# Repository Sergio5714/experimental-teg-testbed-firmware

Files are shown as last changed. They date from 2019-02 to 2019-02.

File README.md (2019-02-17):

# Experimental TEG (thermoelectric generator) testbed firmware
**Author: Sergei Vostrikov**

This repository contains embedded software and the PCBs for the experimental testbed.

**The main function of the testbed:**
* Imitate heat exchange, thermoelectric and electric proceses 
in the wearable thermoelectric generator.

**Testbed's subsystems enable:**
* Low speed (>= _5 Hz_) temperature measurements with an accuracy better than _0.15°K_;
* Temperature difference stabilization (temperature swing <=_12°K_, stabilization error <= _0.1°K_);
* Two channels ADC measurements (accuracy >= _1 mv_) in a range of approximately _0 - 100 mV_;
* Real time [data visialization](https://github.com/Sergio5714/experimental-teg-testbed-gui).

**Used technologies/tools:** C, Keil uVision, STM32F4, FreeRTOS, Jupyter, KiCAD, Peltier modules.

Detailed description can be found in the 
[pdf manual](https://github.com/Sergio5714/experimental-teg-testbed-firmware/blob/master/docs/Description_experimental_teg_testbed.pdf).

**The main PCB:**



**The temperature sensor PCB:**

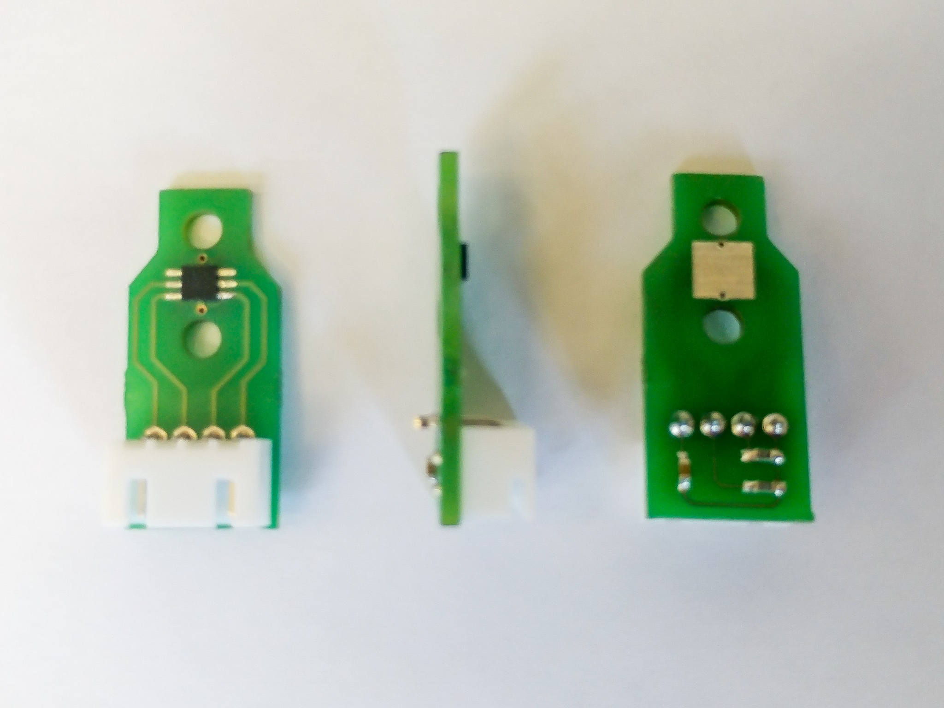
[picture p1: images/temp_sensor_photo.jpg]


**The testbed simplified schematic:**

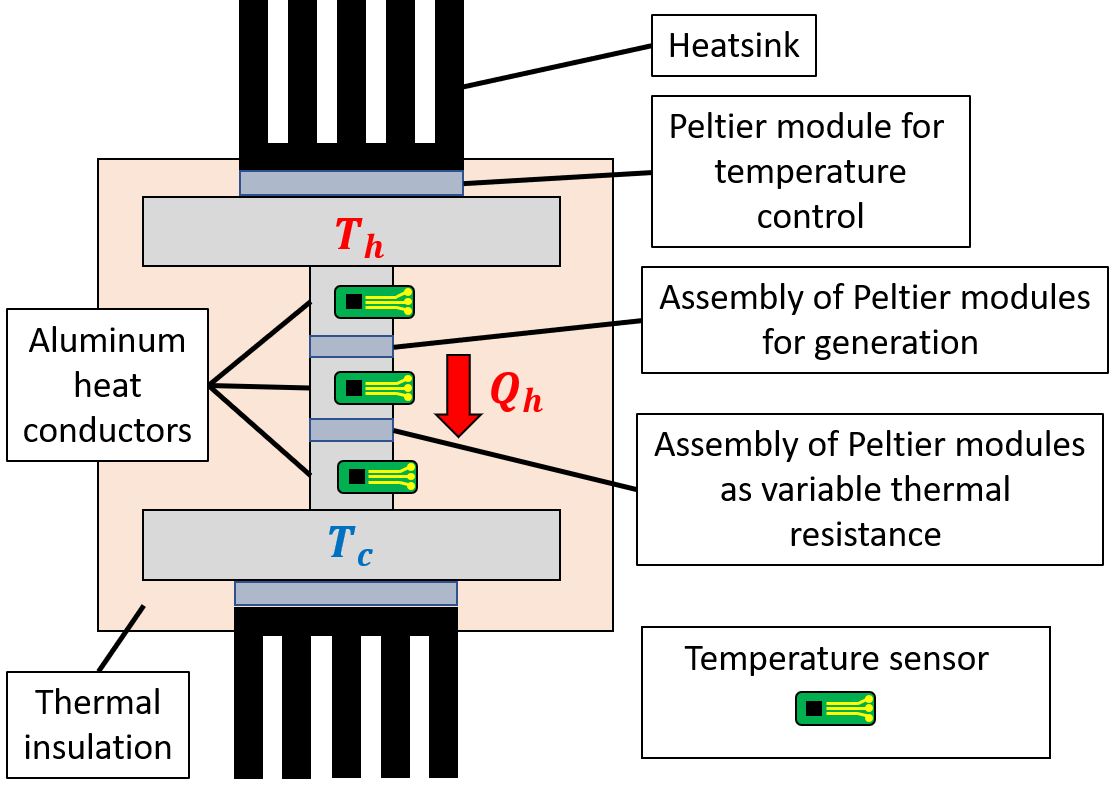
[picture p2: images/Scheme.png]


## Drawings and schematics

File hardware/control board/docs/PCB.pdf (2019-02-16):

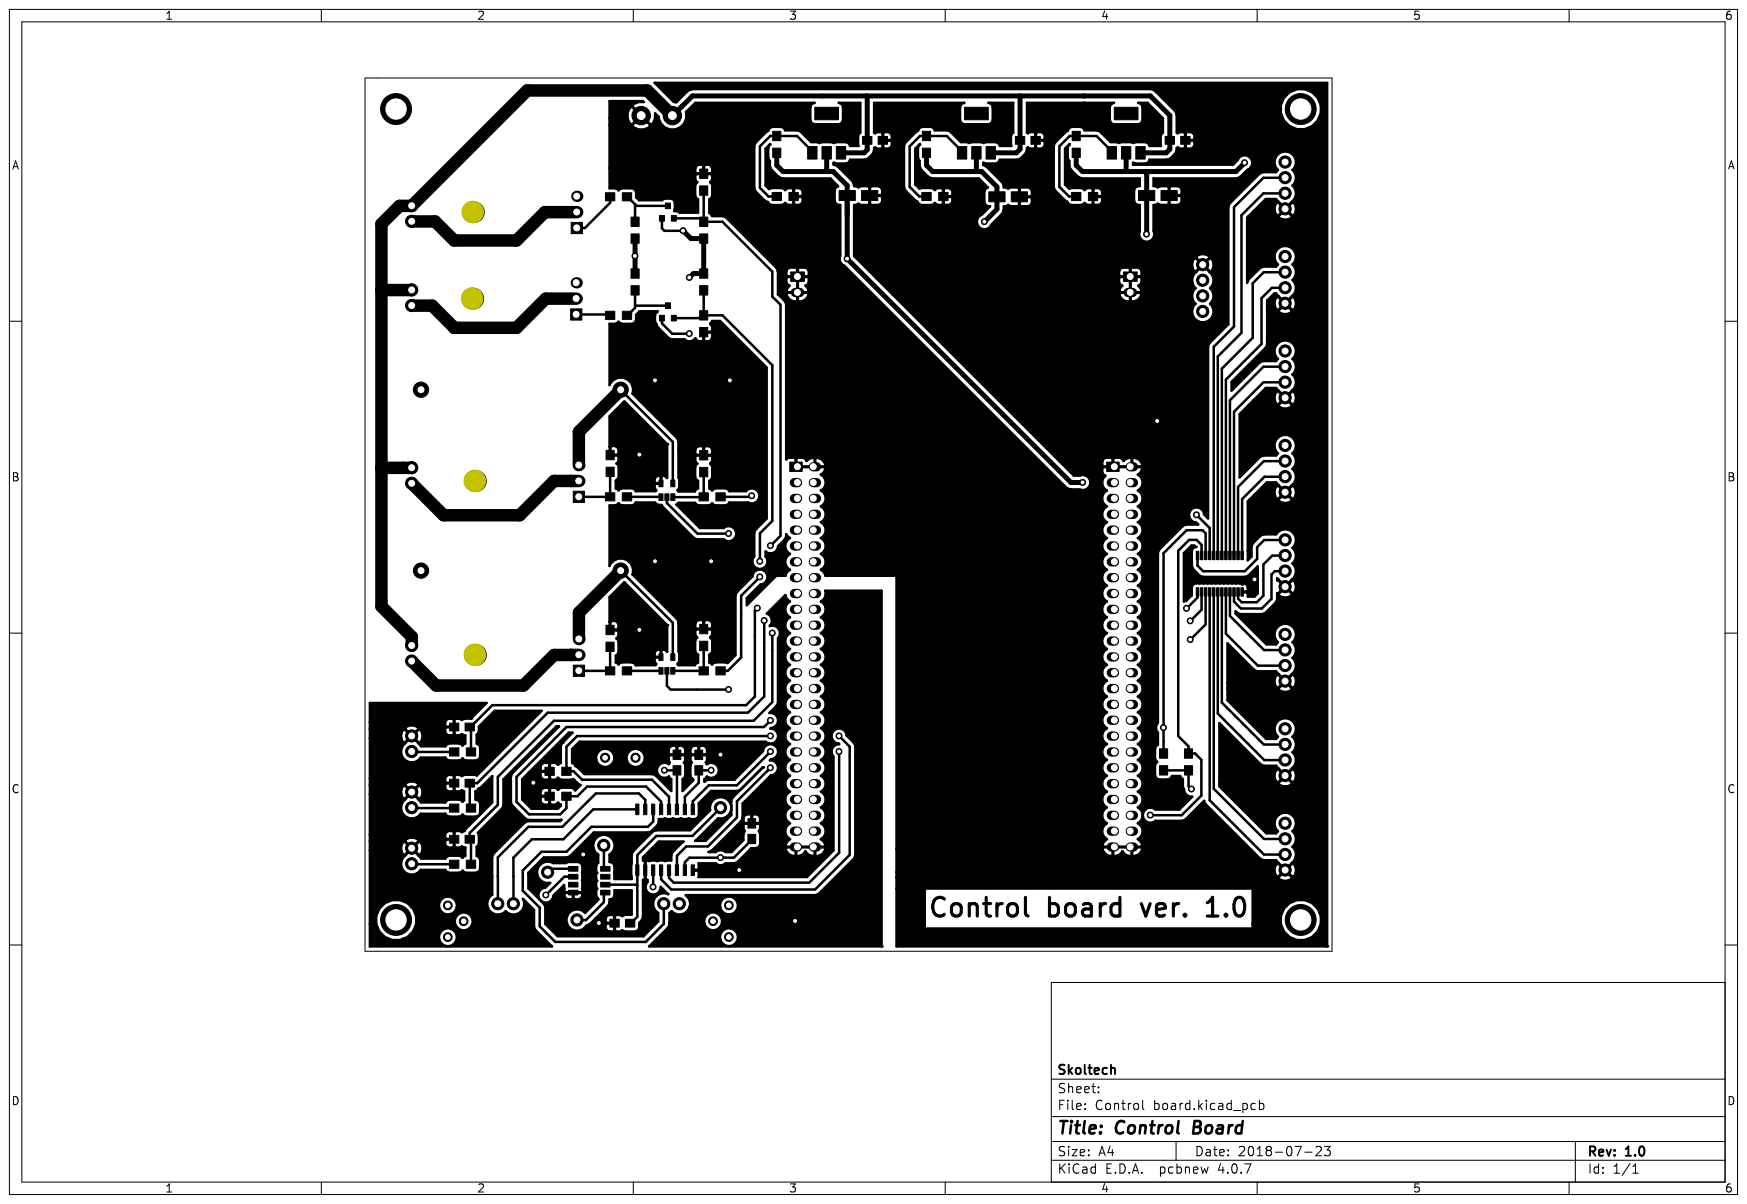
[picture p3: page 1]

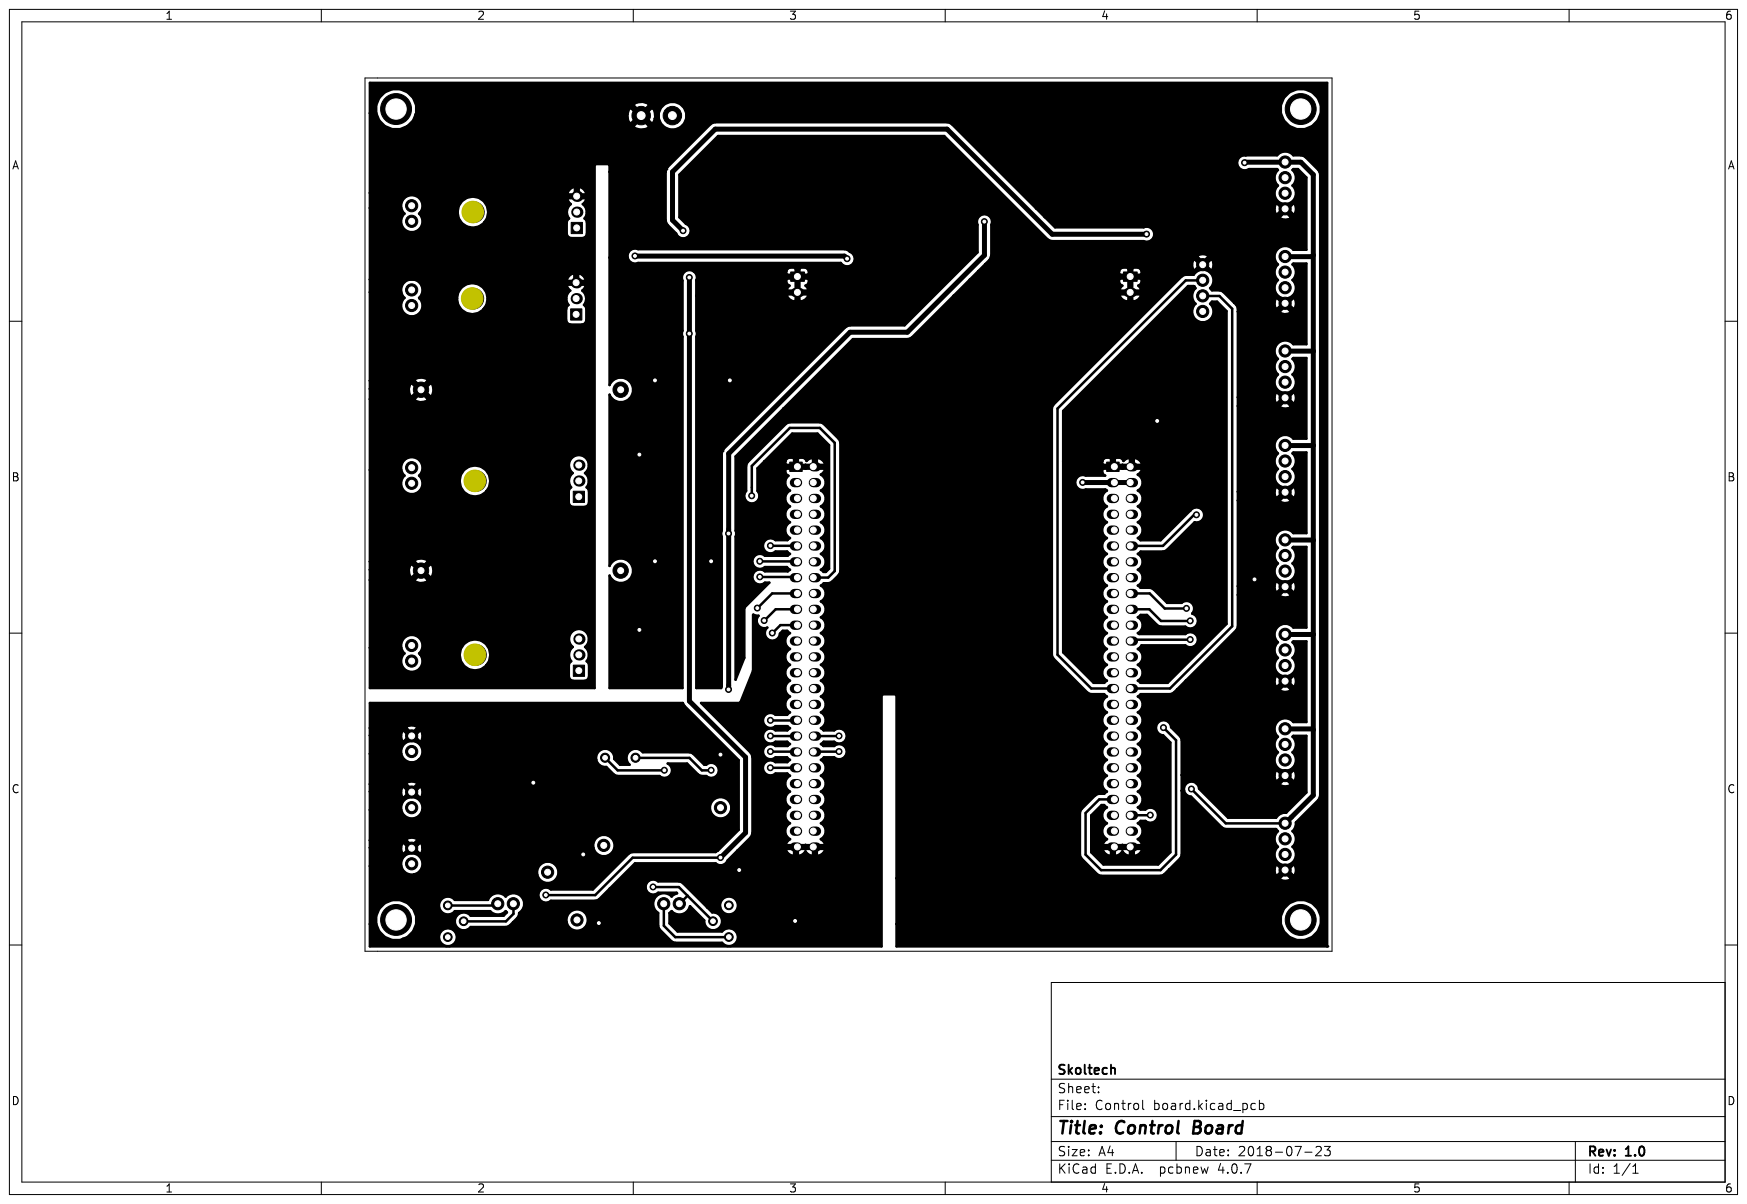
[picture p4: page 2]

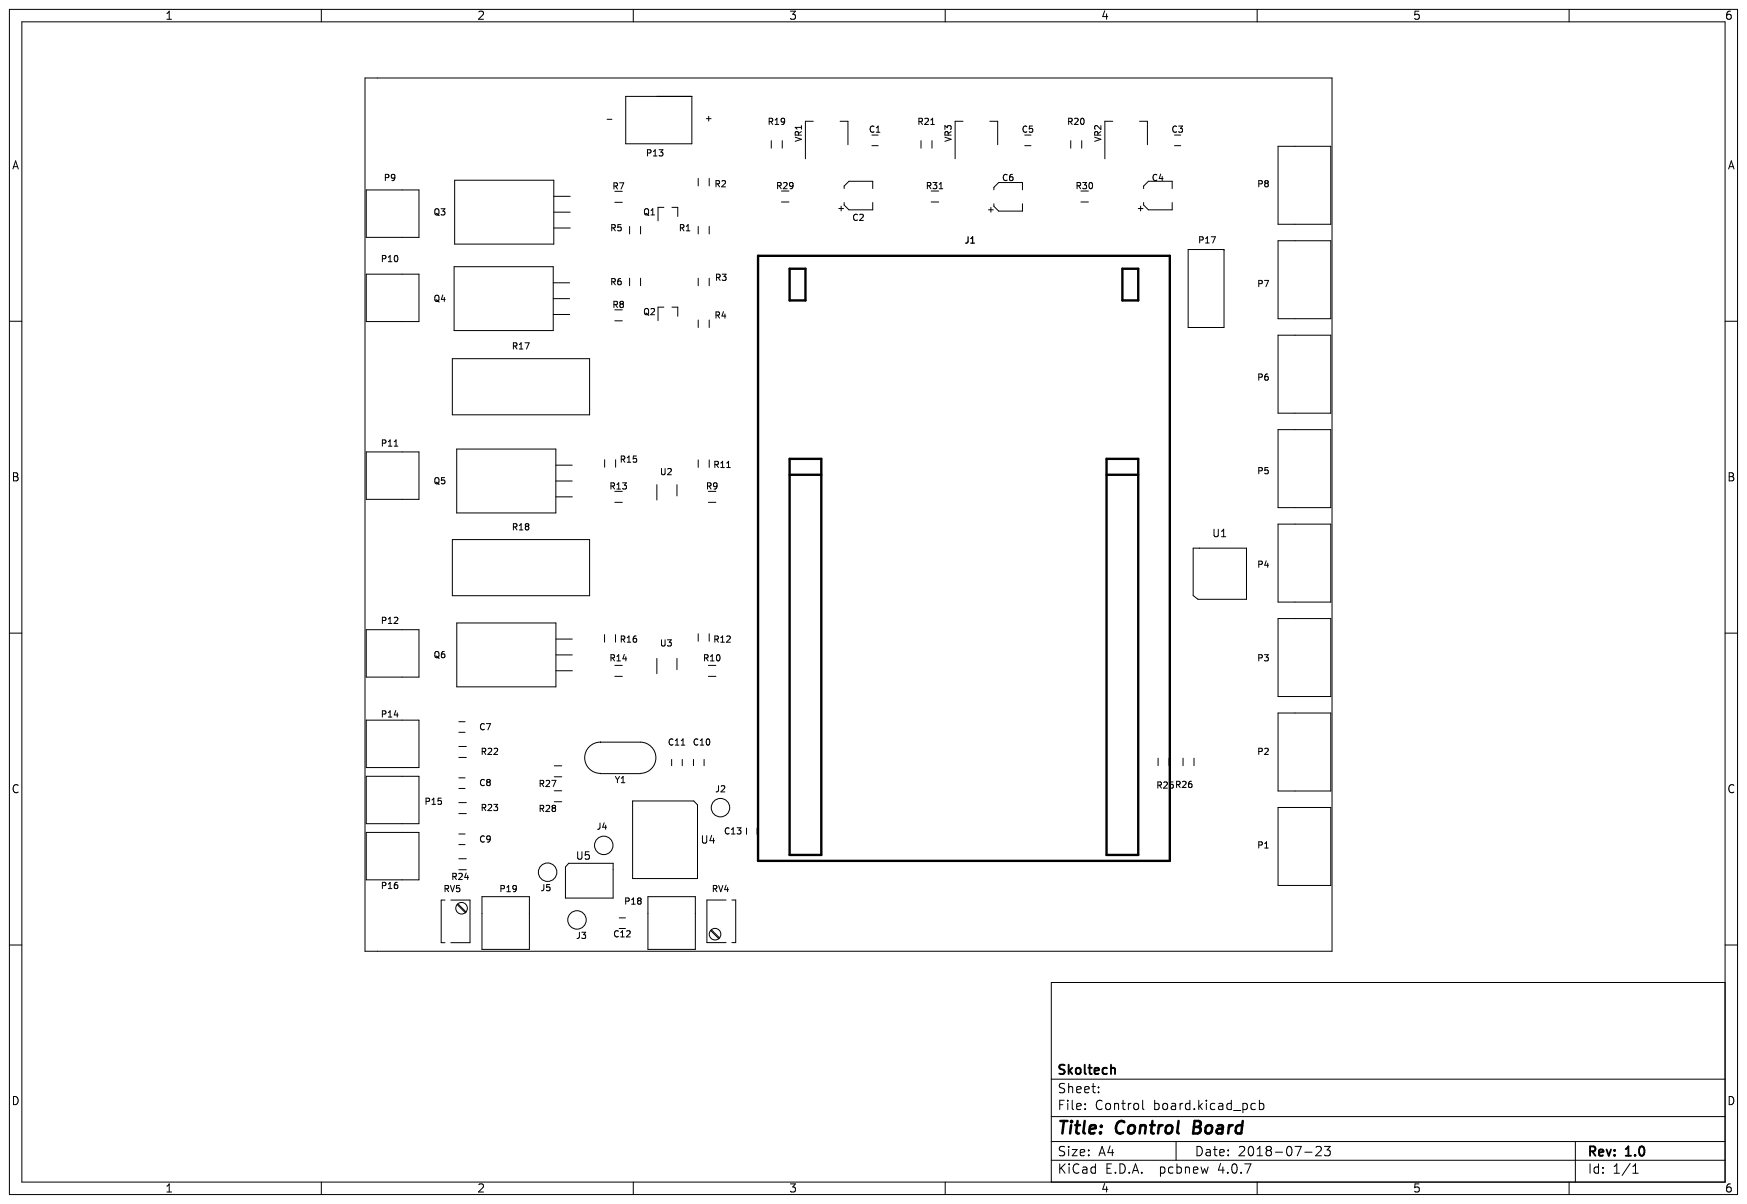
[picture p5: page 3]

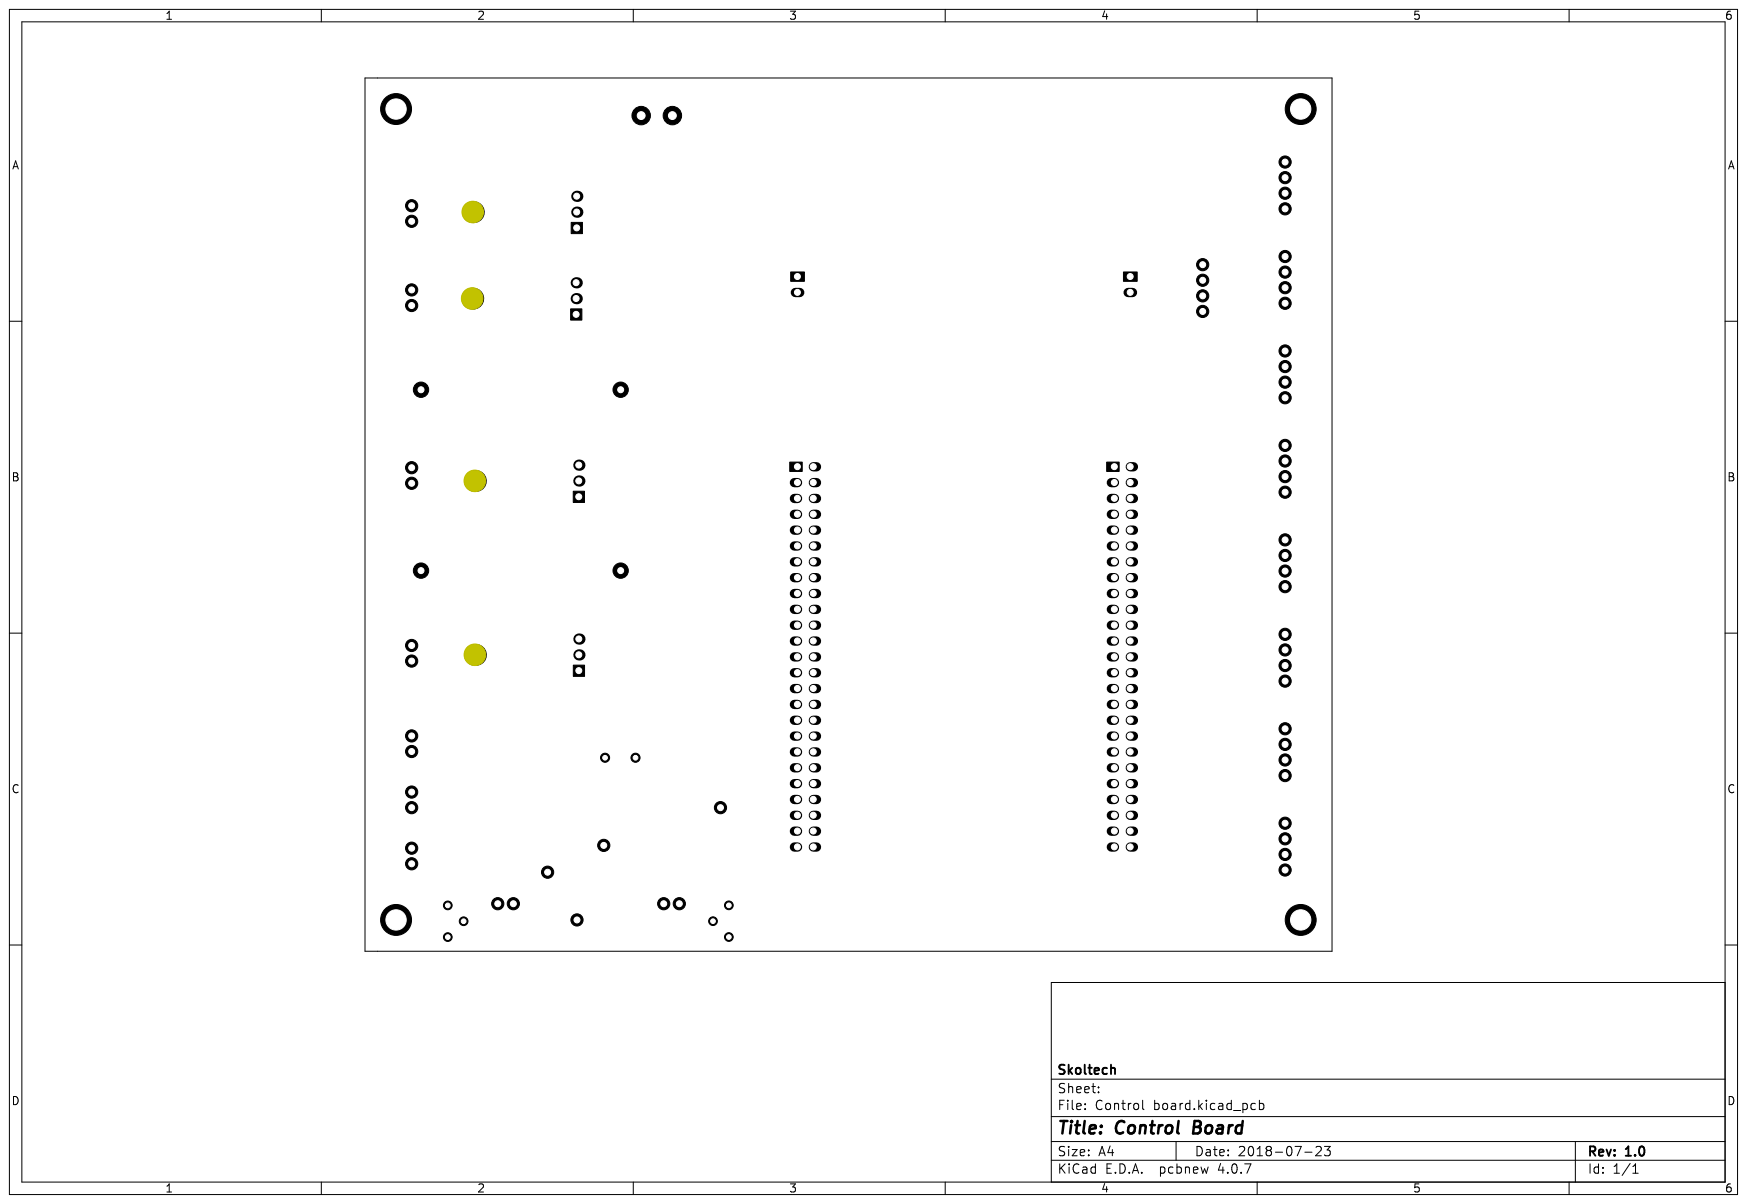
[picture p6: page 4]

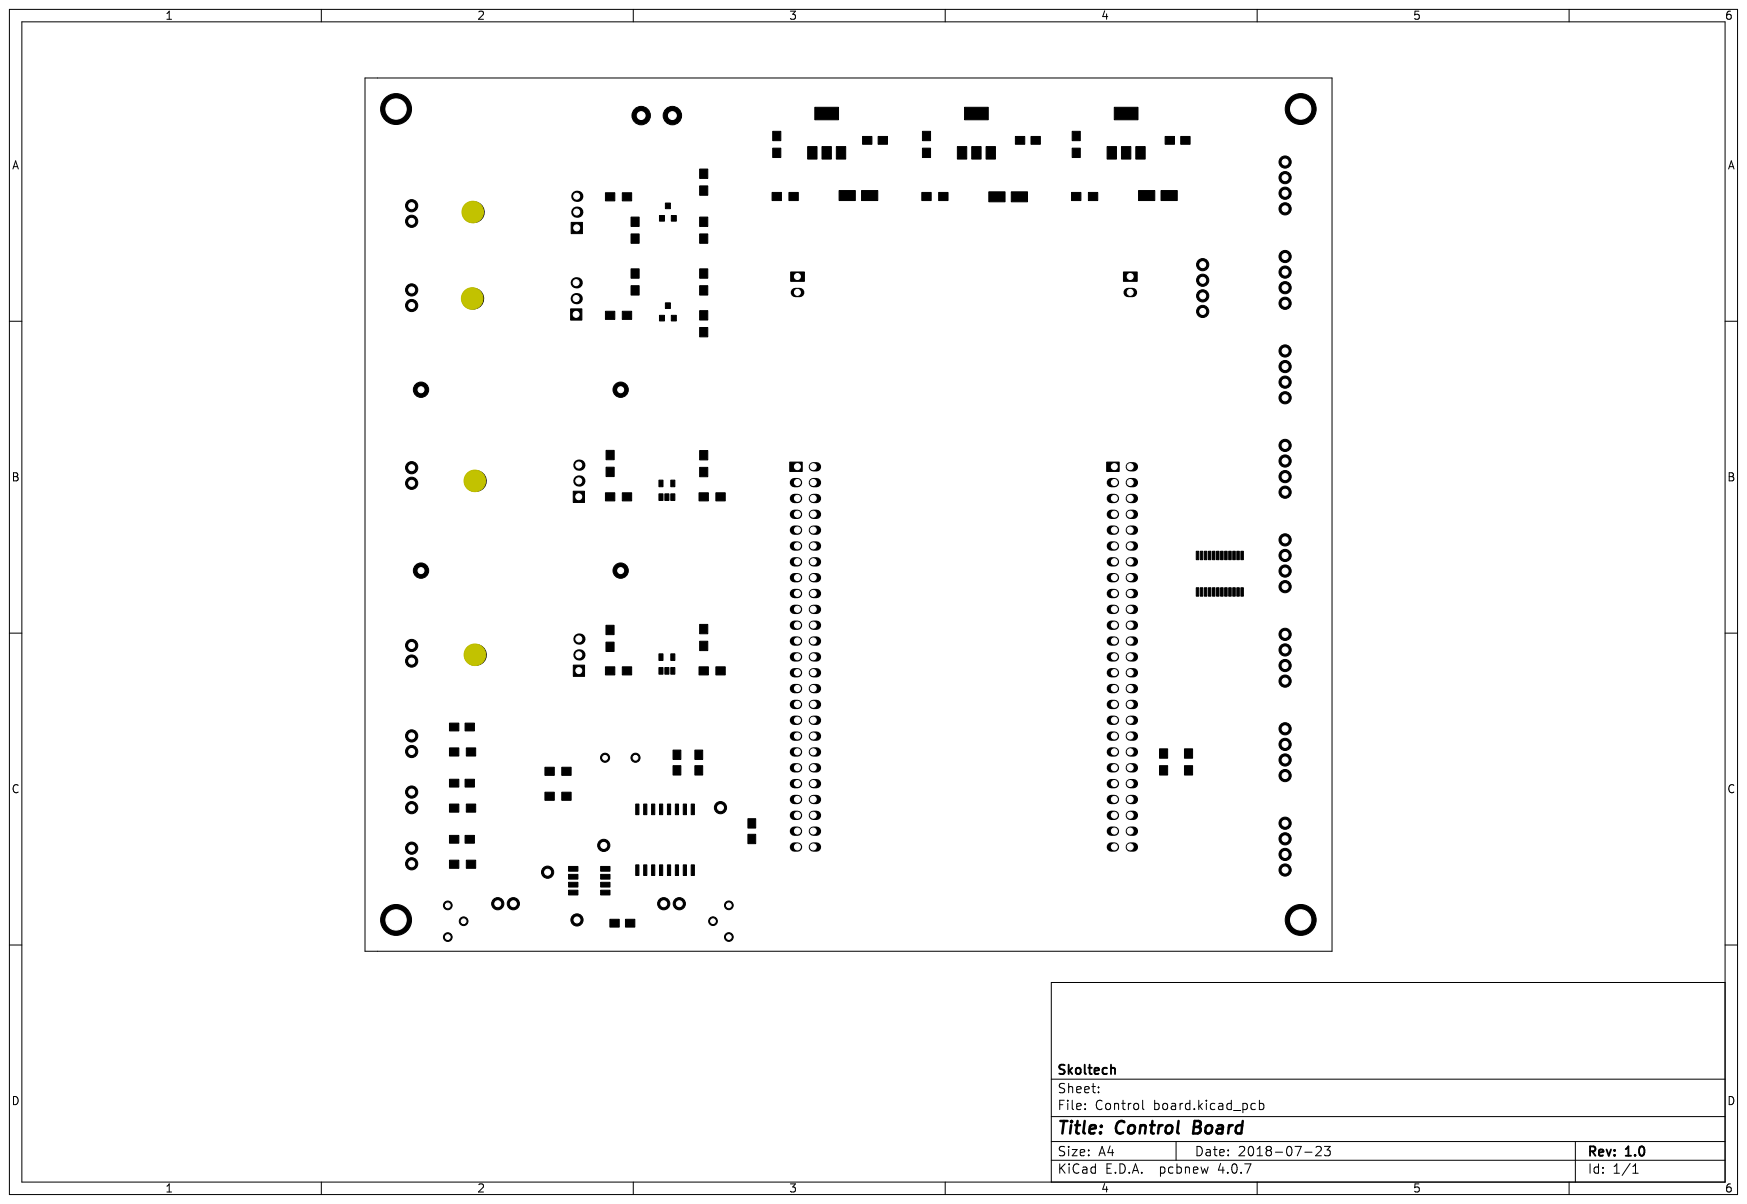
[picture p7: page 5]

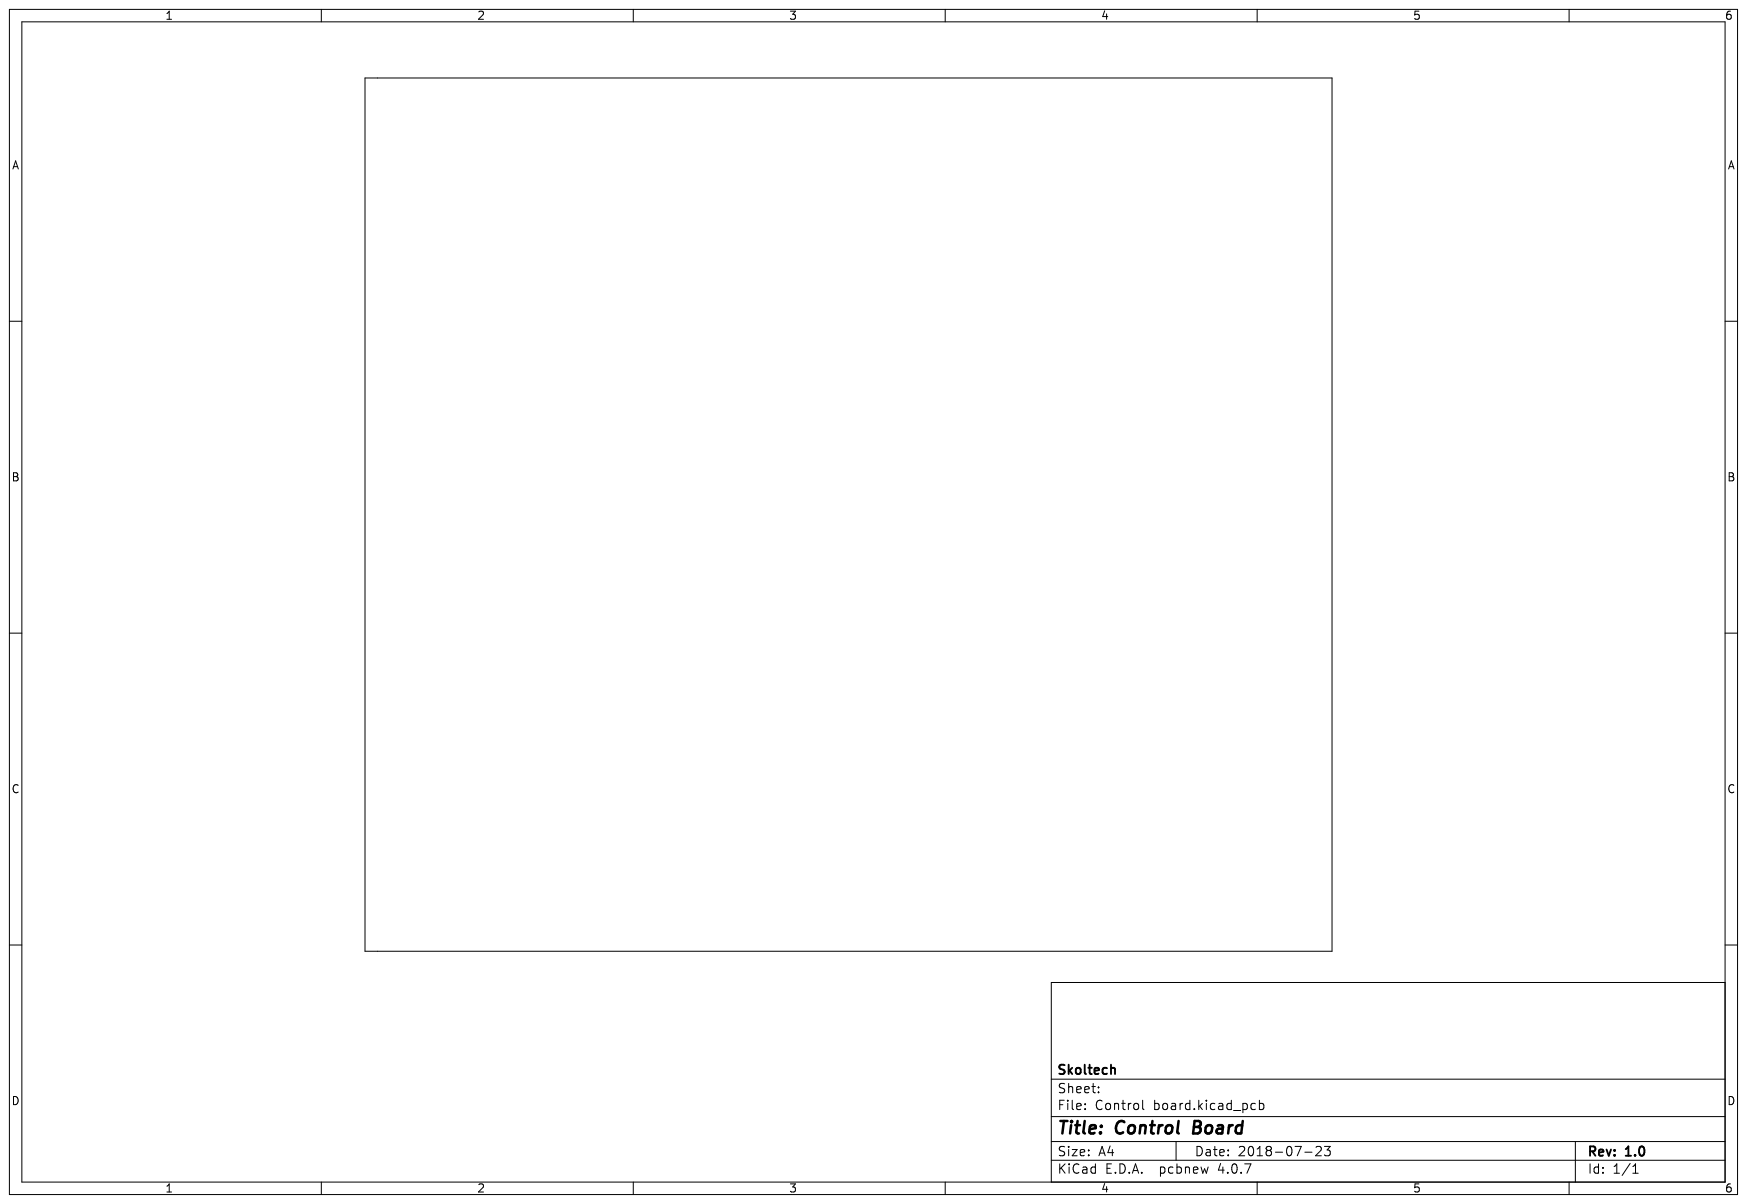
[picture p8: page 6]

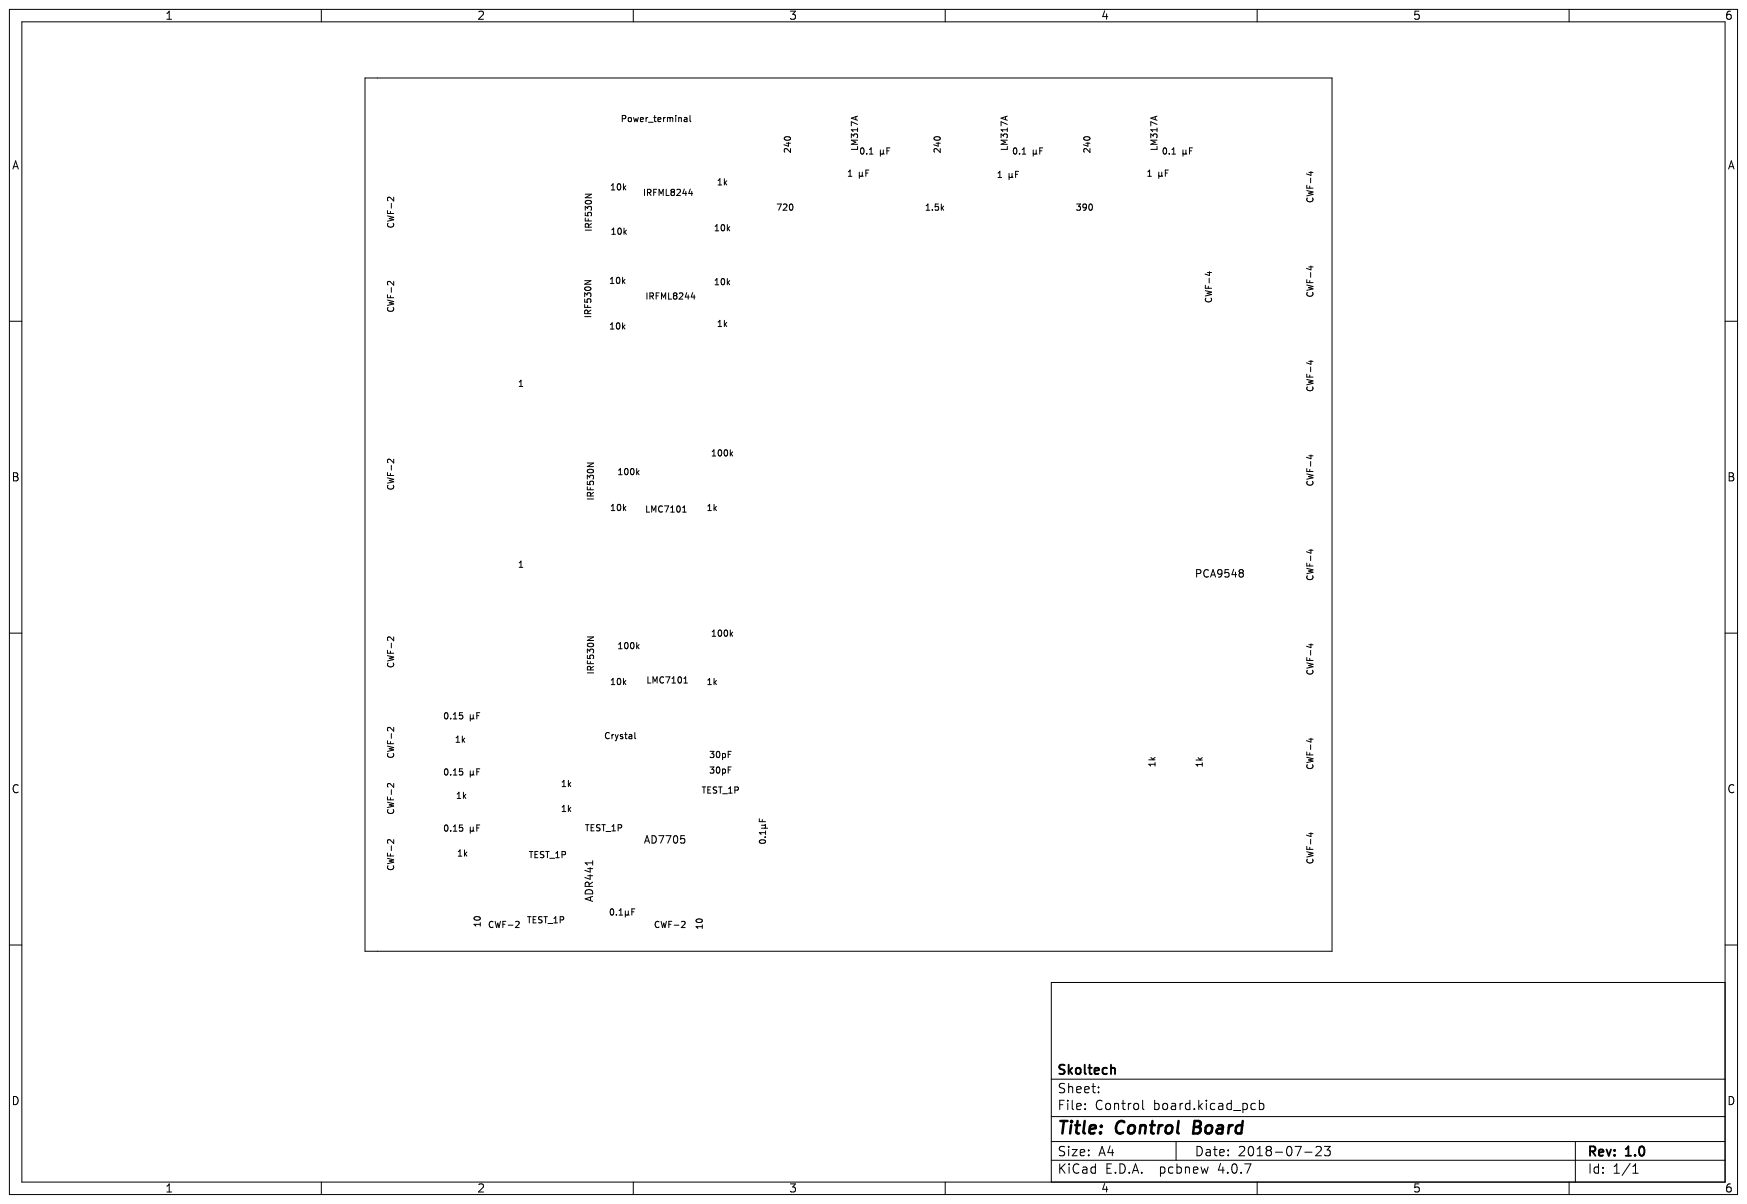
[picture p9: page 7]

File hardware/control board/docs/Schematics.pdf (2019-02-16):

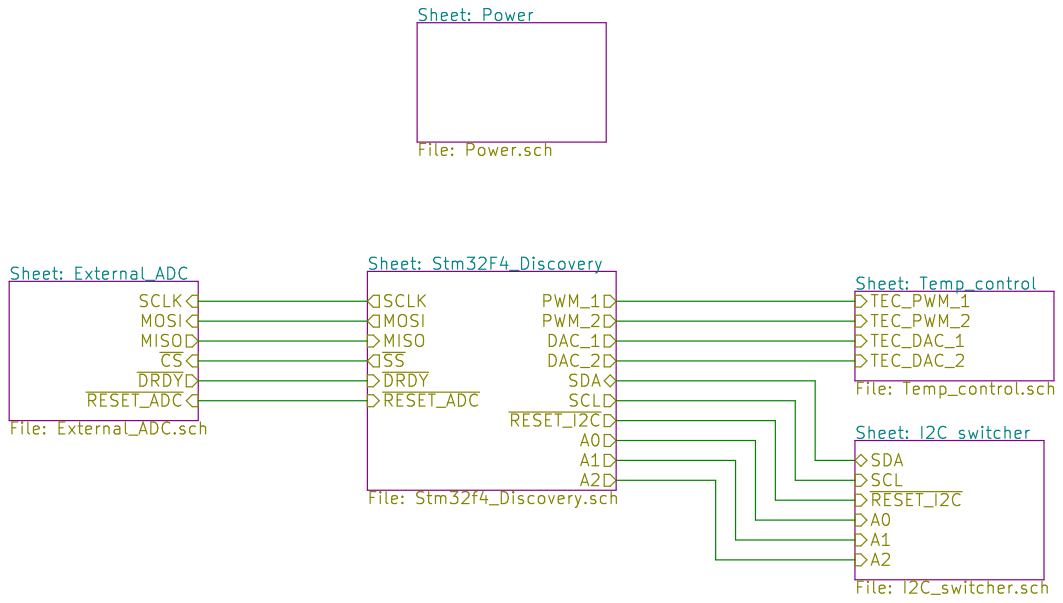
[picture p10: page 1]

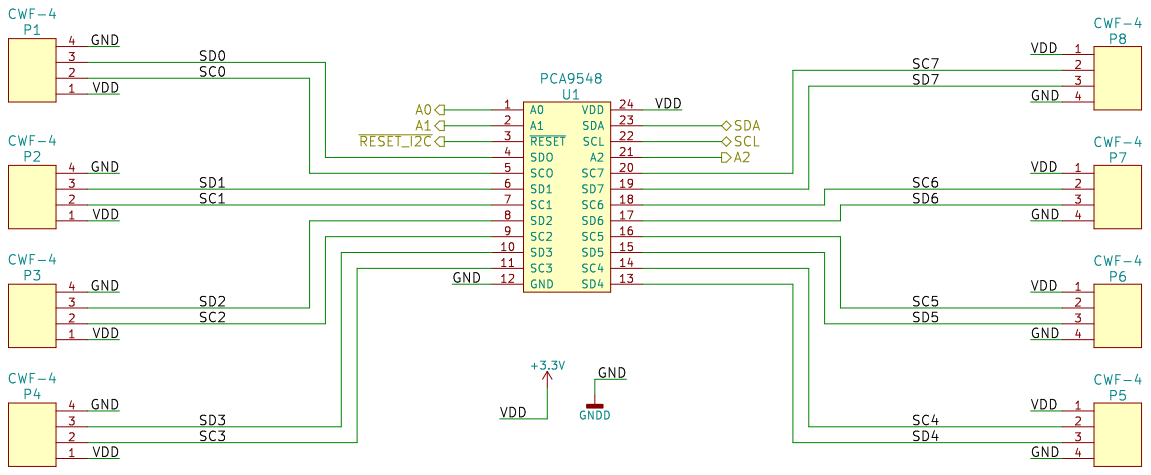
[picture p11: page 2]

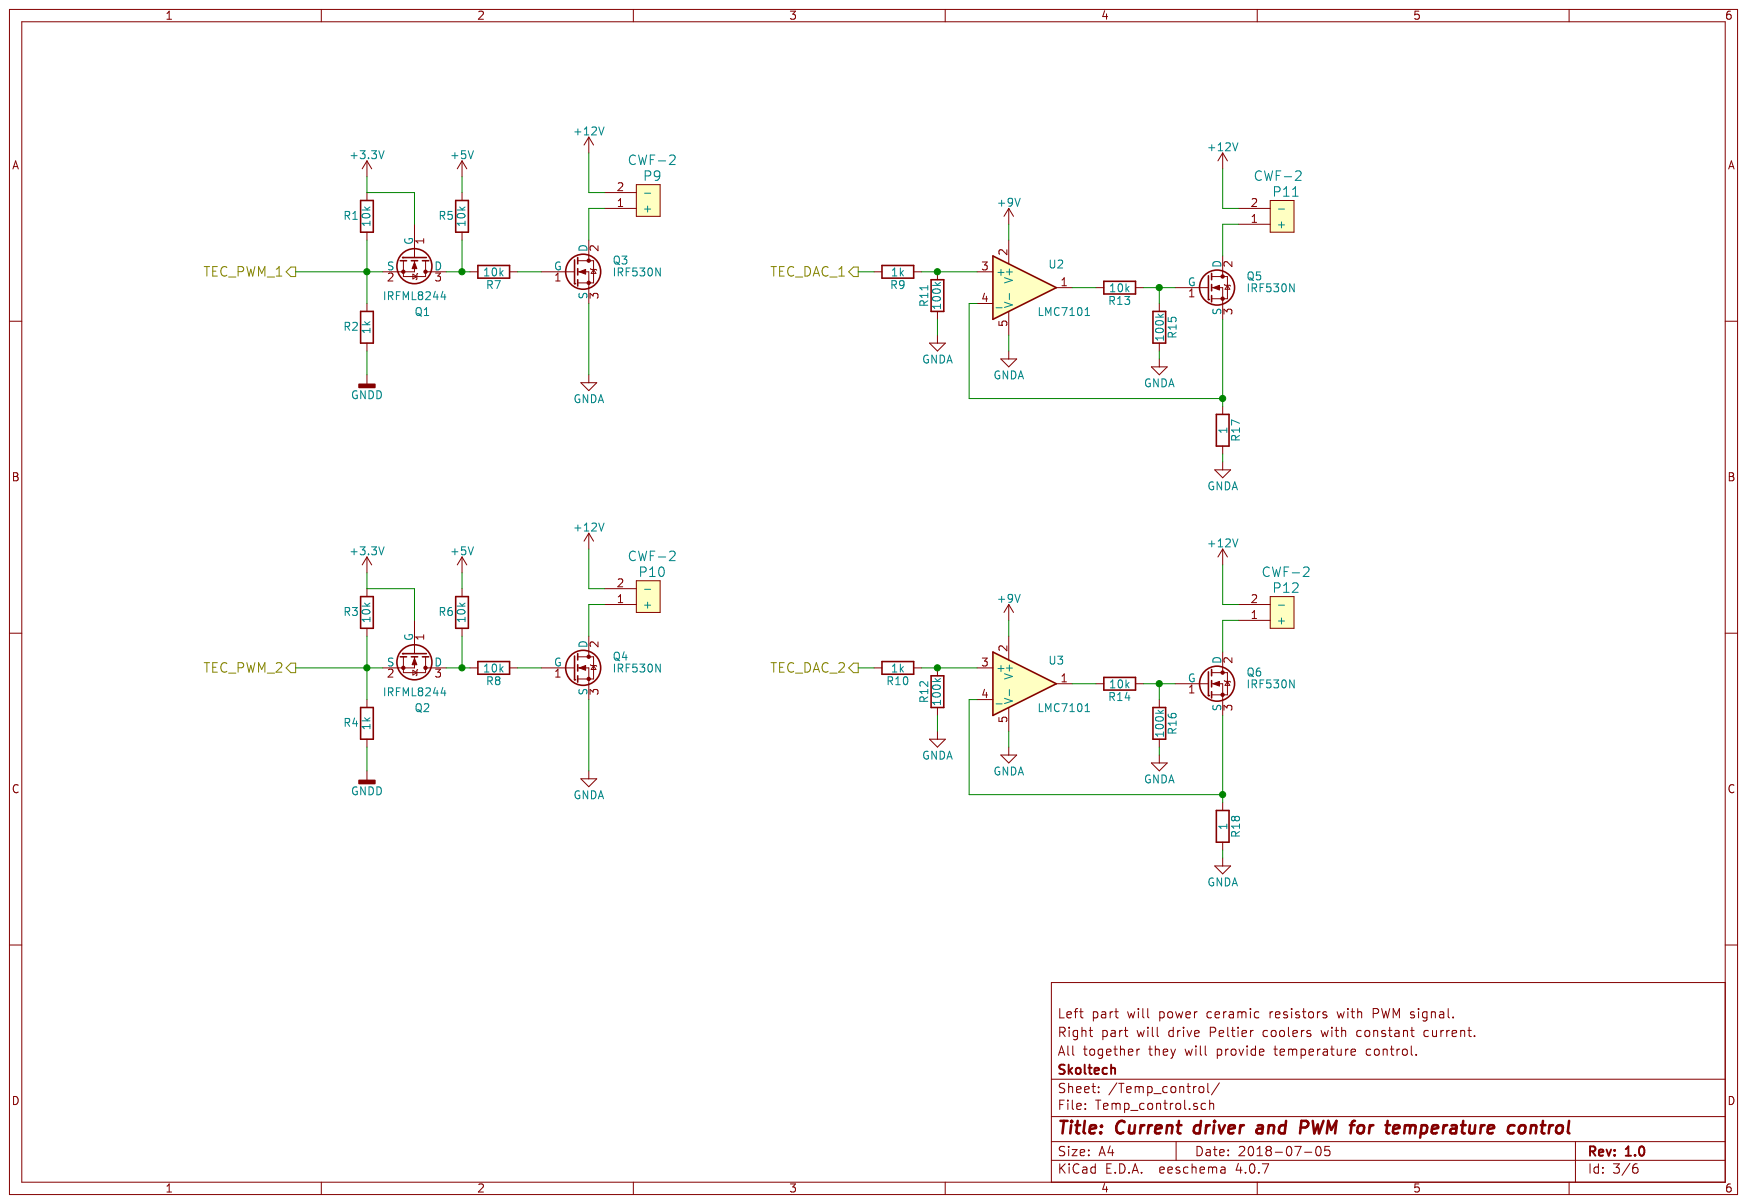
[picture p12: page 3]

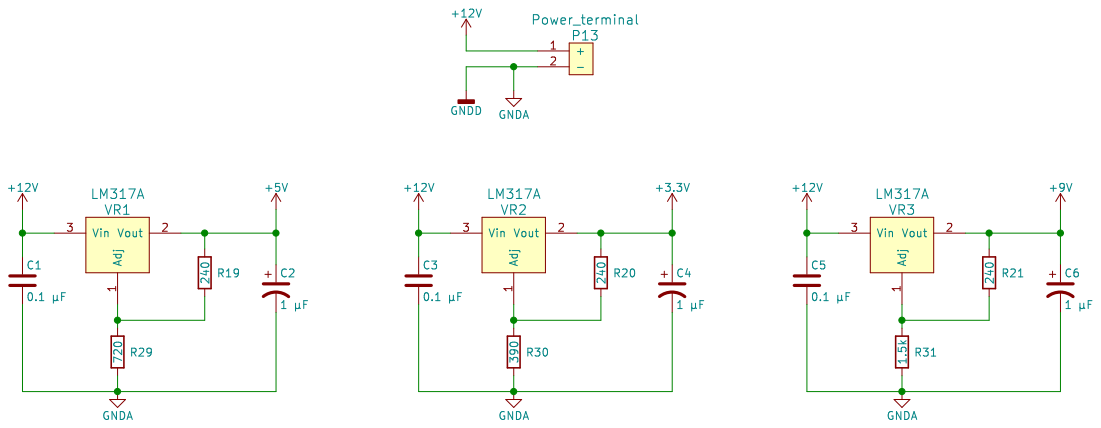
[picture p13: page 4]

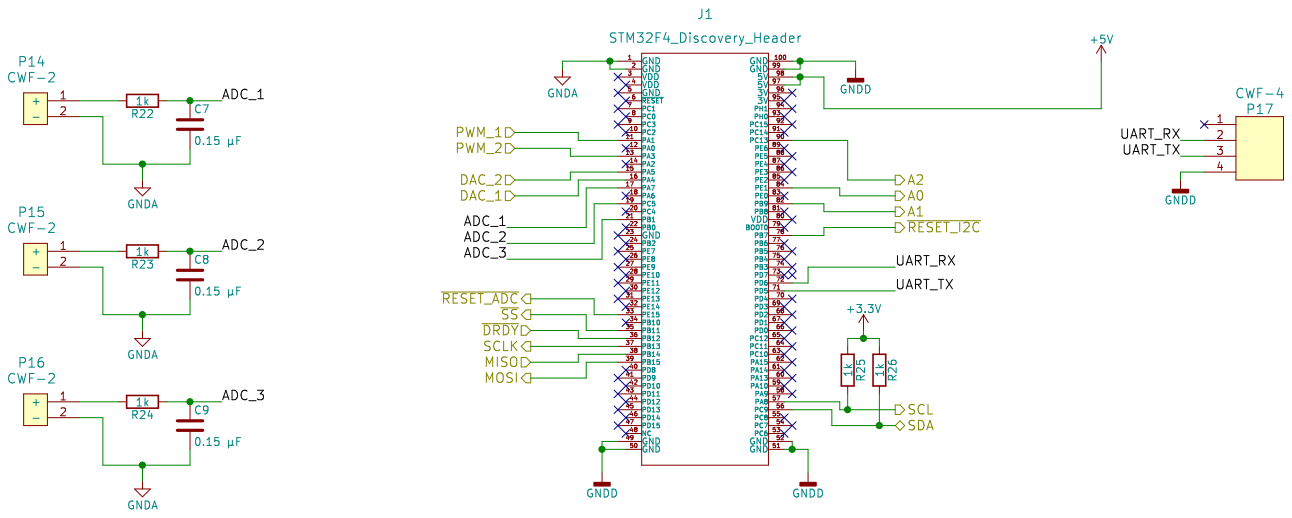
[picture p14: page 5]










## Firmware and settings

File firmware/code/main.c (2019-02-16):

#include "stm32f4xx.h"
#include "Board.h"
#include "Communication.h"

#include "FreeRTOS.h"
#include "task.h"
#include "queue.h"

#include "Si7051.h"
#include "I2C_switcher.h"
#include "AD7705.h"
#include "Facility.h"
#include "Interrupts.h"
#include "Shift_reg.h"

// I2C module for temperature sensor
extern I2C_Module_With_State_Typedef I2CModule;

// SPI module
extern SPI_Module_With_State_Typedef SPIModule;

// Time of start of operation
extern uint32_t timeOfStart;

float voltagesADC[2];

Pid_Regulator_Struct_Typedef tempRegulatorHot;
Pid_Regulator_Struct_Typedef tempRegulatorCold;

extern Temp_Sensors_Typedef tempSensors;

uint8_t selector;
uint16_t counter;

void taskReadTemps(void * arg)
{
	while(1)
	{
		if (tempSensors.errorFlags[5] == TEMP_SENSOR_MEASURING)
		{
			// Read temperatures
			tempSensorsReadTemperatures();
			// Filter value
			filterTemperatures();
		}
		
		// Start temperature measurements
		tempSensorsStartMeasurements();
		
		tempRegulatorHot.current = tempSensors.temperatures[7];
		
		tempRegulatorCold.current = tempSensors.temperatures[5];
		
		pidCalc(&tempRegulatorHot);
		pidCalc(&tempRegulatorCold);

		// DAC
		DAC->DHR12R2 = ((uint16_t)((tempRegulatorHot.output / 3.0f) * 4095)) & 0xfff;
		DAC->DHR12R1 = ((uint16_t)((tempRegulatorCold.output / 3.0f) * 4095)) & 0xfff;
		
		// Software trigger
		DAC->SWTRIGR |= DAC_SWTRIGR_SWTRIG1 | DAC_SWTRIGR_SWTRIG2;
		
		vTaskDelay(100);
	}
	vTaskDelete( NULL );
}
void taskCheckFan(void * arg)
{
	while(1)
	{
		float dutyCycle = (tempRegulatorCold.output + tempRegulatorHot.output)/ (tempRegulatorCold.maxOutput + tempRegulatorHot.maxOutput);
		if (dutyCycle > 0.2f)
		{
			timPwmChangeDutyCycle(FAN_PWM_TIM_MODULE, FAN_CH1_NUMBER , 1.0f);
		}
		else
		{
			timPwmChangeDutyCycle(FAN_PWM_TIM_MODULE, FAN_CH1_NUMBER , 0.0f);
		}
		vTaskDelay(10000);
	}
	vTaskDelete( NULL );
}

void taskReadVoltages(void * arg)
{
	while(1)
	{
		if (counter < 2)
		{
			counter++;
		}
		switch(selector)
		{
			case 0x00:
			{
				if(counter < 2)
				{
					float tempValue;
					adcReadResult(ADC_CHN_AIN1, &tempValue);
				}
				else
				{
					adcReadResult(ADC_CHN_AIN1, &voltagesADC[0]);
				}
				counter++;
				break;
			}
			case 0x01:
			{
				if(counter < 2)
				{
					float tempValue;
					adcReadResult(ADC_CHN_AIN2, &tempValue);
				}
				else
				{
					adcReadResult(ADC_CHN_AIN2, &voltagesADC[1]);
				}
				counter++;
				break;
			}
		}
		// Change channel
		if(counter == 5)
		{
			if (selector == 0)
				selector = 1;
			else if (selector == 1)
				selector = 0;
			counter = 0;
		}
		vTaskDelay(50);
	}
	vTaskDelete( NULL );
}


void taskUartProcessing(void * arg)
{
	while (1)
	{
		getPackage();
		checkCommandAndExecute();
		vTaskDelay(20);
	}
	vTaskDelete( NULL );
}

void dacInit()
{
	// Enable clock for DAC
	RCC->APB1ENR |= RCC_APB1ENR_DACEN;
	
	// GPIO
	gpioInitPin(GPIOA, GPIO_Pin_4, GPIO_MODE_IN, GPIO_OUTPUT_MODE_OD, GPIO_PUPD_NOPULL);
	gpioInitPin(GPIOA, GPIO_Pin_5, GPIO_MODE_IN, GPIO_OUTPUT_MODE_OD, GPIO_PUPD_NOPULL);
	
	// Event Trigger enabled 
	DAC->CR |= DAC_CR_TEN1 | DAC_CR_TEN2;
	
	// Software trigger
	DAC->CR |= DAC_CR_TSEL1 | DAC_CR_TSEL2;
	
	// Enable
	DAC->CR |= DAC_CR_EN1;
	DAC->CR |= DAC_CR_EN2;
}

void setup(void)
{
	// Init board perpherial
    boardInitAll();
	
	// Init shift register
	shiftRegSetup();
	
	delayInTenthOfMs(20); // 2 ms
	
	// Init switcher of I2C bus
	initGpioI2CSwitcher();
	
	// Initialize all temperature sensors
	tempSensorsInit();
	
	delayInTenthOfMs(1000); // 100 ms
	
	// Initialization of AD7705
	adcReset();
	
	// Init channels of ADC
	if(adcInit(ADC_CHN_AIN2, ADC_UPDATE_RATE_25) == ERROR)
	{
		// Error
		timPwmChangeDutyCycle(LED_PWM_TIM_MODULE, TIM_PWM_CHANNEL_1, 0.8);
	};
	if (adcInit(ADC_CHN_AIN1, ADC_UPDATE_RATE_25) == ERROR)
	{
		// Error
		timPwmChangeDutyCycle(LED_PWM_TIM_MODULE, TIM_PWM_CHANNEL_1, 0.8);
	};
	
	// Initialization of internal DAC
	dacInit();
	
	// Temperature control init
	pidInit(&tempRegulatorHot, 10.0f, 50.0f, 0.04f, 0.0f, 2.0f, 30.0f);
	pidInit(&tempRegulatorCold, -10.0f, -50.0f, -0.04f, 0.0f, 2.0f, 30.0f);
	
	// Enable timer for temp sensors
	//timEnable(TEMP_MEASUREMENTS_TIM_MODULE);	
}

int main()
{	
	// Setup all
	setup();
	
	if (xTaskCreate(taskReadTemps, "Temperature measurements", 128, NULL, 1, NULL) != pdTRUE)
	{
		// Error
		timPwmChangeDutyCycle(LED_PWM_TIM_MODULE, TIM_PWM_CHANNEL_1, 0.8);
	}
	
	if (xTaskCreate(taskReadVoltages, "Voltage measurements", 128, NULL, 1, NULL) != pdTRUE)
	{
		// Error
		timPwmChangeDutyCycle(LED_PWM_TIM_MODULE, TIM_PWM_CHANNEL_1, 0.8);
	}
	if (xTaskCreate(taskUartProcessing, "Uart", 128, NULL, 1, NULL) != pdTRUE)
	{
		// Error
		timPwmChangeDutyCycle(LED_PWM_TIM_MODULE, TIM_PWM_CHANNEL_1, 0.8);
	}
	if (xTaskCreate(taskCheckFan, "Fan", 128, NULL, 1, NULL) != pdTRUE)
	{
		// Error
		timPwmChangeDutyCycle(LED_PWM_TIM_MODULE, TIM_PWM_CHANNEL_1, 0.8);
	}
	vTaskStartScheduler();
	
	while (1)
	{
		
	}
}

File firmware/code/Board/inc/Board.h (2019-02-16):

#ifndef STM32F4_BOARD
#define STM32F4_BOARD

#include "STM32F4_GPIO.h"
#include "STM32F4_TIM.h"
#include "STM32F4_UART.h"
#include "STM32F4_RCC.h"
#include "STM32F4_I2C.h"
#include "STM32F4_EXTI.h"
#include "STM32F4_SPI.h"
#include "Interrupts.h"

//--------------------------------------------- I2C module ---------------------------------------------------//
#define I2C_MODULE                       I2C3
#define I2C_MODULE_EVENT_IRQN            I2C3_EV_IRQn
#define I2C_MODULE_ERROR_IRQN            I2C3_ER_IRQn
#define I2C_MODULE_PIN_AF                GPIO_AF_I2C3
#define I2C_MODULE_SDA_PIN_PORT          GPIOC
#define I2C_MODULE_SDA_PIN_NUMBER        GPIO_Pin_9
#define I2C_MODULE_SCL_PIN_PORT          GPIOA
#define I2C_MODULE_SCL_PIN_NUMBER        GPIO_Pin_8

//--------------------------------------------- USART modules ------------------------------------------------//

#define COM_USART_MODULE                 USART2
#define COM_USART_IRQN                   USART2_IRQn
#define COM_USART_BAUDRATE               250000
#define COM_USART_PIN_AF                 GPIO_AF_USART1
#define COM_USART_TX_PIN_PORT            GPIOD
#define COM_USART_TX_PIN_NUMBER          GPIO_Pin_5
#define COM_USART_RX_PIN_PORT            GPIOD
#define COM_USART_RX_PIN_NUMBER          GPIO_Pin_6

//--------------------------------------------- SPI module ---------------------------------------------------//

#define SPI_MODULE                       SPI2
#define SPI_IRQN                         SPI2_IRQHandler
#define SPI_MOSI_PORT                    GPIOB
#define SPI_MOSI_PIN                     GPIO_Pin_15
#define SPI_MISO_PORT                    GPIOB
#define SPI_MISO_PIN                     GPIO_Pin_14
#define SPI_SCLK_PORT                    GPIOB
#define SPI_SCLK_PIN                     GPIO_Pin_13

//--------------------------------------------- LED PWM control  ----------------------------------------------//

// ARR = 42000, PSC = 2, fapb1 = 42 MHZ, PWM frequency = 1000 Hz
#define LED_PWM_TIM_MODULE               TIM4
#define LED_PWM_TIM_PSC                  0x02
#define LED_PWM_TIM_ARR                  0xA410
#define LED_PWM_PIN_AF                   GPIO_AF_TIM4

#define LED_CH1_NUMBER                   0x01
#define LED_CH2_NUMBER                   0x02
#define LED_CH3_NUMBER                   0x03
#define LED_CH4_NUMBER                   0x04

#define LED_CH_PWM_PORT                  GPIOD
#define LED_CH1_PWM_PIN                  GPIO_Pin_12
#define LED_CH2_PWM_PIN                  GPIO_Pin_13
#define LED_CH3_PWM_PIN                  GPIO_Pin_14
#define LED_CH4_PWM_PIN                  GPIO_Pin_15

//--------------------------------------------- Fan PWM control  ----------------------------------------------//

// ARR = 42000, PSC = 2, fapb1 = 42 MHZ, PWM frequency = 1000 Hz
#define FAN_PWM_TIM_MODULE               TIM2
#define FAN_PWM_TIM_PSC                  0x02
#define FAN_PWM_TIM_ARR                  0xA410
#define FAN_PWM_PIN_AF                   GPIO_AF_TIM2

#define FAN_CH1_NUMBER                   0x02
#define FAN_CH2_NUMBER                   0x04

#define FAN_CH_PWM_PORT                  GPIOA
#define FAN_CH1_PWM_PIN                  GPIO_Pin_1
#define FAN_CH2_PWM_PIN                  GPIO_Pin_3

//--------------------------------------------- Timer for temperature measurements (10 Hz) -------------------//

// ARR = 42000, PSC = 200, fapb1 = 42 MHZ, Frequency = 10 Hz
#define TEMP_MEASUREMENTS_TIM_MODULE     TIM14
#define TEMP_MEASUREMENTS_TIM_PSC        0xC8
#define TEMP_MEASUREMENTS_TIM_ARR        0xA410
#define TEMP_MEASUREMENTS_IRQN           TIM8_TRG_COM_TIM14_IRQn
#define TEMP_MEASUREMENTS_PERIOD         0.02f

//--------------------------------------------- GPIO for LED -------------------------------------------------//
#define COLL_AVOID_LED_PIN               GPIO_Pin_2
#define COLL_AVOID_LED_PORT              GPIOD

//--------------------------------------------- Timer for local time in one tenth of a ms (10000 Hz) ---------//
// ARR = 4200, PSC = 2, fapb1 = 42 MHZ, Frequency = 10000 Hz
#define LOCAL_TIME_TIM_MODULE            TIM7
#define LOCAL_TIME_TIM_PSC               0x02
#define LOCAL_TIME_TIM_ARR               0x1068
#define LOCAL_TIME_IRQN                  TIM7_IRQn
#define LOCAL_TIME_PERIOD                0.0001f


// Initialize all necessary peripheral devices
void boardInitAll(void);

// Indicate error
void showError(void);

// Indicate error
void showNoError(void);

#endif

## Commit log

2018-11-05 Shift register for automatic load switching was added
2019-02-16 Folders were rearranged and PCB projects were added
    [Control board-B.Cu.gbr, Control board-B.Mask.gbr, Control board-Edge.Cuts.gbr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]
